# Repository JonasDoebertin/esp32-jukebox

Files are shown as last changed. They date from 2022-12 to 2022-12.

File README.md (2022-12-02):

# Jukebox

An ESP32 based jukebox driven by ESPHome and Home Assistant.

---

About the project: it’s a simple ESP32 based media player that allows scanning cards with RFID tags to select the media to play. Everything will be tight together with ESPHome (for the ESP32 firmware side) and Home Assistant.

It’s a simple 2-layer board with 1.6mm thickness and 4cm x 6cm overall size.

The board features the following main parts:

- ESP32-WROOM-32E as the MCU
- AMS1117-3.3 as a power regulator
- CH340C as the serial converter
- MAX98357AETE+T as a DAC with integrated 3w amp
- connectors for three simple buttons (volume -/+, play/pause)
- connector for an PN532 based RFID module connected via I2C
- connector for a passive broadband speaker

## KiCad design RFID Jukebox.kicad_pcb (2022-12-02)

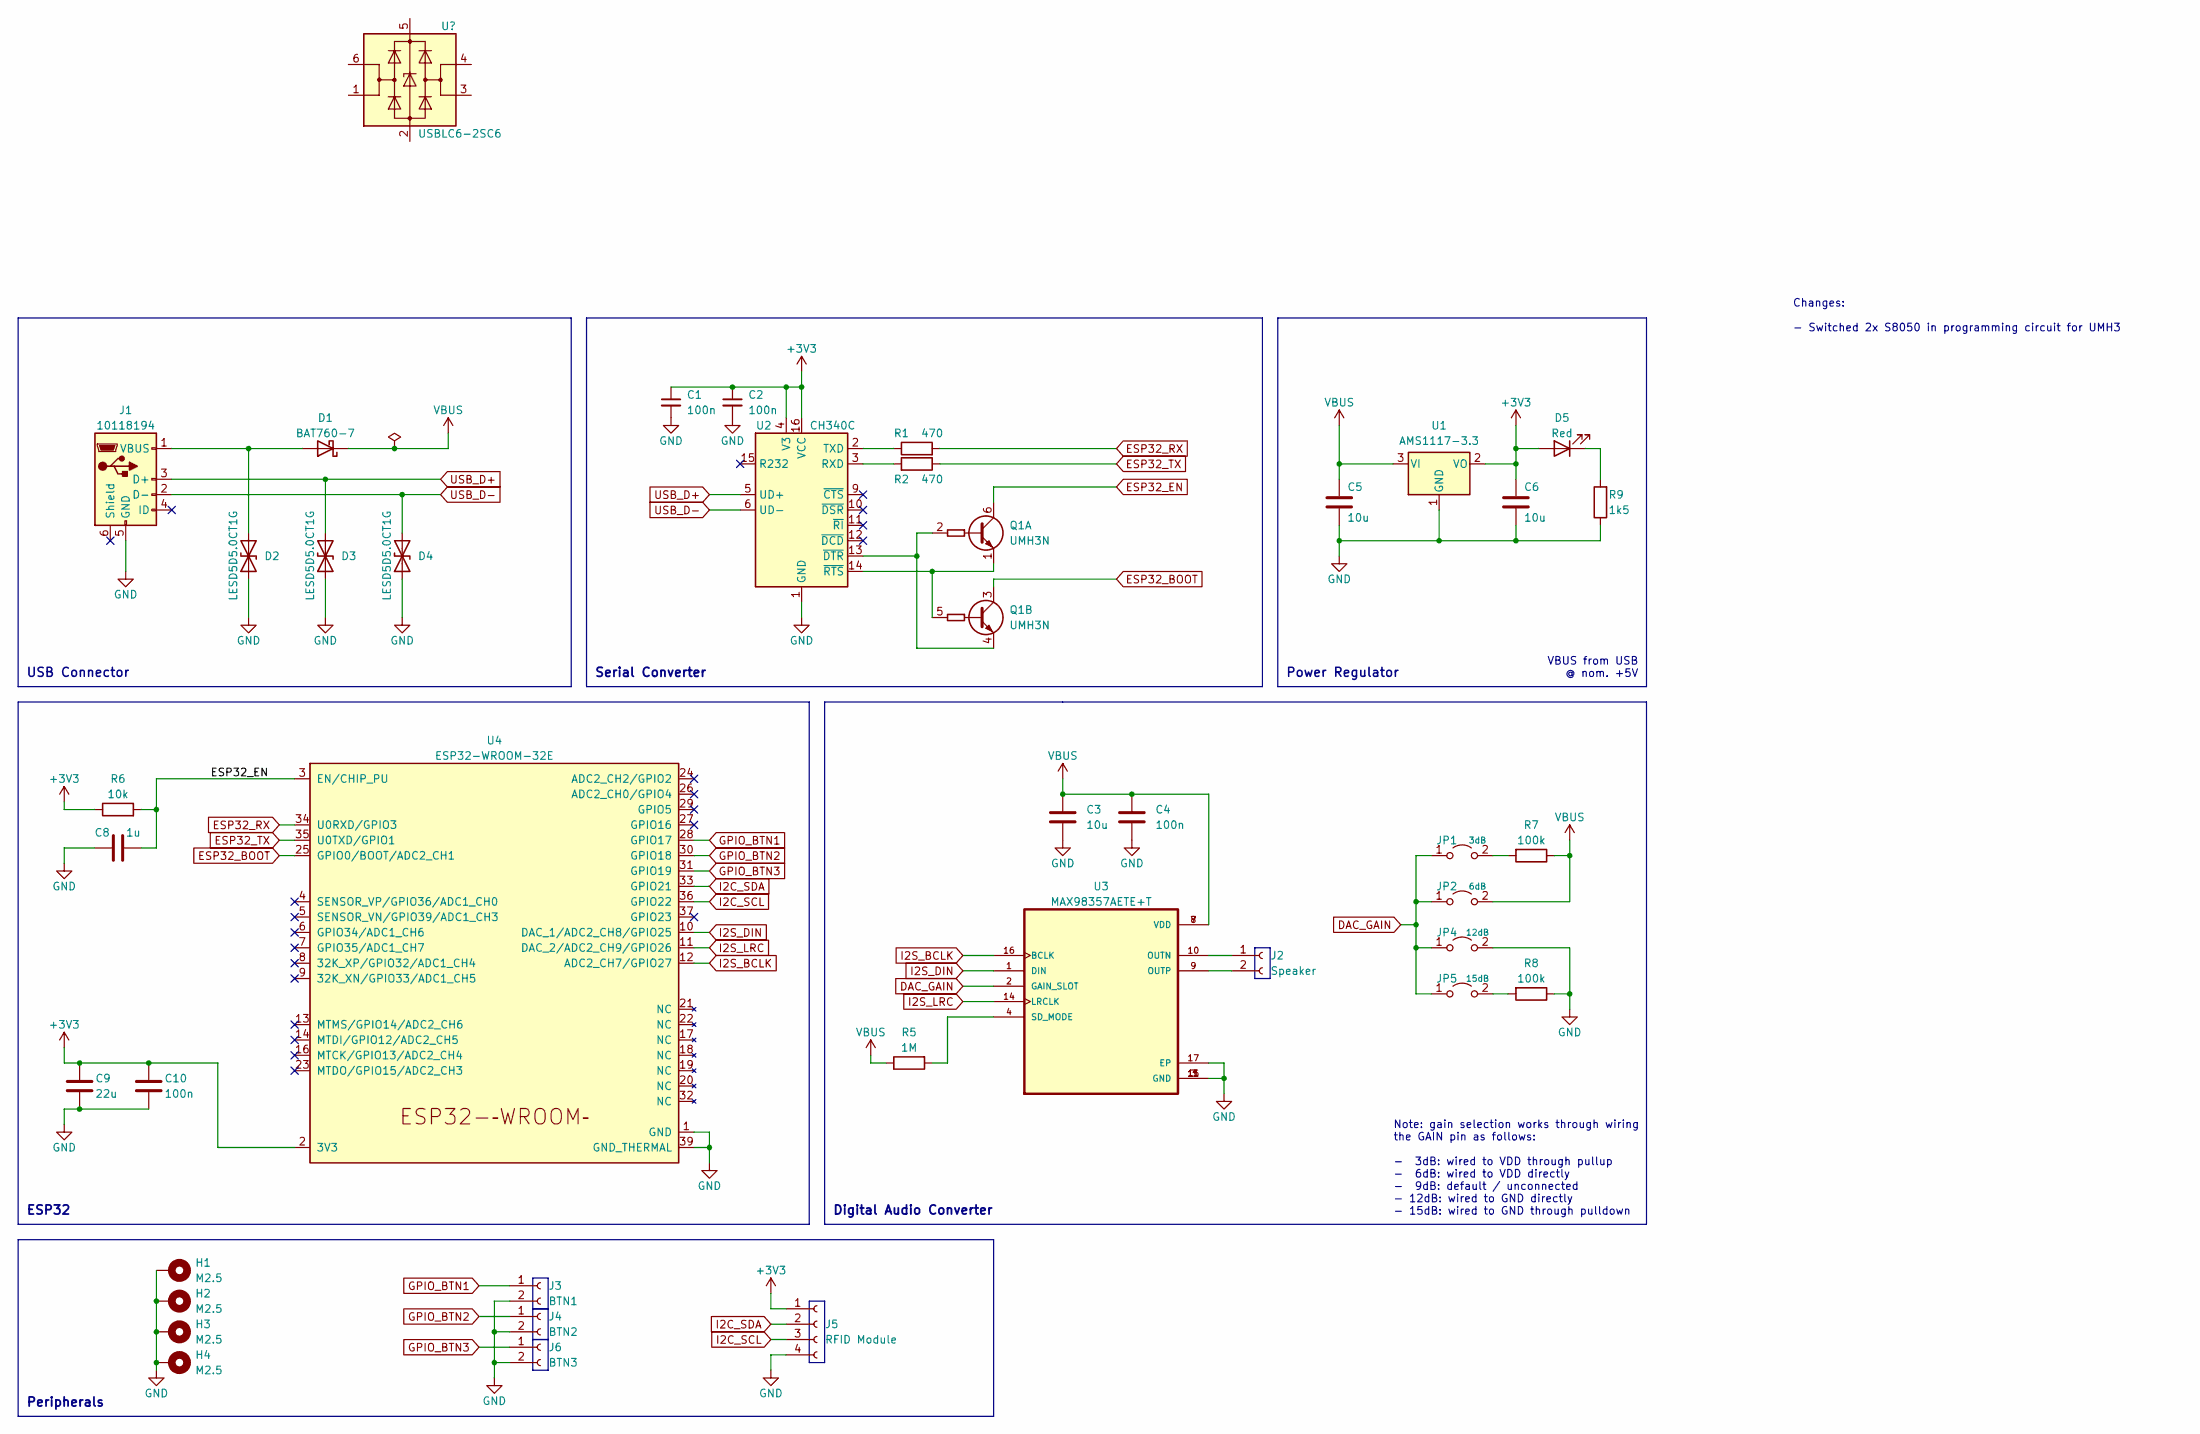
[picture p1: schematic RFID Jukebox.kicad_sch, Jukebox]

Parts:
C1, C2, C4, C10: 100n; C_0603_1608Metric; LCSC C14663
C3: 10u; C_0603_1608Metric; LCSC C96446
C5, C6: 10u; C_0805_2012Metric; LCSC C15850
C8: 1u; C_0603_1608Metric; LCSC C15849
C9: 22u; C_0805_2012Metric; LCSC C45783
D1: BAT760-7; D_SOD-323; LCSC C124187
D2, D3, D4: LESD5D5.0CT1G; D_SOD-523; LCSC C383211
D5: Red; LED_0603_1608Metric; LCSC C2286
H1, H2, H3, H4: M2.5; MountingHole_2.7mm_M2.5_Pad_Via
J1: 10118194; USB_Micro-B_Amphenol_10118194_Horizontal; LCSC C132563
J2: Speaker; Molex_KK-254_AE-6410-02A_1x02_P2.54mm_Vertical
J3: BTN1; Molex_KK-254_AE-6410-02A_1x02_P2.54mm_Vertical
J4: BTN2; Molex_KK-254_AE-6410-02A_1x02_P2.54mm_Vertical
J5: RFID Module; Molex_KK-254_AE-6410-04A_1x04_P2.54mm_Vertical
J6: BTN3; Molex_KK-254_AE-6410-02A_1x02_P2.54mm_Vertical
JP1: 3dB; PinHeader_1x02_P2.54mm_Vertical
JP2: 6dB; PinHeader_1x02_P2.54mm_Vertical
JP4: 12dB; PinHeader_1x02_P2.54mm_Vertical
JP5: 15dB; PinHeader_1x02_P2.54mm_Vertical
Q1: UMH3N; SOT-363_SC-70-6; LCSC C62892
R1, R2: 470; R_0603_1608Metric; LCSC C23179
R5: 1M; R_0805_2012Metric; LCSC C17514
R6: 10k; R_0603_1608Metric; LCSC C25804
R7, R8: 100k; R_0603_1608Metric; LCSC C25803
R9: 1k5; R_0603_1608Metric; LCSC C22843
U1: AMS1117-3.3; SOT-223-3_TabPin2; LCSC C6186
U2: CH340C; SOIC-16_3.9x9.9mm_P1.27mm; LCSC C84681
U3: MAX98357AETE+T; TQFN-16-1EP_3x3mm_P0.5mm_EP1.23x1.23mm; LCSC C910544
U4: ESP32-WROOM-32E; LCSC C701341

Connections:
+3V3: C1.1, C2.1, C6.1, C9.1, C10.1, D5.2 (A), J5.1, R6.1, U1.2 (VO), U2.4 (V3), U2.16 (VCC), U4.2 (3V3)
DAC_GAIN: JP1.1 (A), JP2.1 (A), JP4.1 (A), JP5.1 (A), U3.2 (GAIN_SLOT)
ESP32_BOOT: Q1.3 (C2), U4.25 (GPIO0/BOOT/ADC2_CH1)
ESP32_EN: C8.2, Q1.6 (C1), R6.2, U4.3 (EN/CHIP_PU)
ESP32_RX: R1.2, U4.34 (U0RXD/GPIO3)
ESP32_TX: R2.1, U4.35 (U0TXD/GPIO1)
GND: C1.2, C2.2, C3.2, C4.2, C5.2, C6.2, C8.1, C9.2, C10.2, D2.1 (A1), D3.1 (A1), D4.1 (A1), H1.1, H2.1, H3.1, H4.1, J1.5 (GND), J3.2, J4.2, J5.4, J6.2, JP4.2 (B), R8.1, R9.1, U1.1 (GND), U2.1 (GND), U3.3 (GND), U3.11 (GND), U3.15 (GND), U3.17 (EP), U4.1 (GND), U4.15 (GND), U4.38 (GND), U4.39 (GND_THERMAL)
GPIO_BTN1: J3.1, U4.28 (GPIO17)
GPIO_BTN2: J4.1, U4.30 (GPIO18)
GPIO_BTN3: J6.1, U4.31 (GPIO19)
I2C_SCL: J5.3, U4.36 (GPIO22)
I2C_SDA: J5.2, U4.33 (GPIO21)
I2S_BCLK: U3.16 (BCLK), U4.12 (ADC2_CH7/GPIO27)
I2S_DIN: U3.1 (DIN), U4.10 (DAC_1/ADC2_CH8/GPIO25)
I2S_LRC: U3.14 (LRCLK), U4.11 (DAC_2/ADC2_CH9/GPIO26)
unnamed: D1.2 (A), D2.2 (A2), J1.1 (VBUS)
unnamed: D5.1 (K), R9.2
unnamed: J2.1, U3.10 (OUTN)
unnamed: J2.2, U3.9 (OUTP)
unnamed: JP1.2 (B), R7.2
unnamed: JP5.2 (B), R8.2
unnamed: Q1.1 (E1), Q1.5 (B2), U2.14 (~RTS)
unnamed: Q1.2 (B1), Q1.4 (E2), U2.13 (~DTR)
unnamed: R1.1, U2.2 (TXD)
unnamed: R2.2, U2.3 (RXD)
unnamed: R5.2, U3.4 (SD_MODE)
USB_D+: D3.2 (A2), J1.3 (D+), U2.5 (UD+)
USB_D-: D4.2 (A2), J1.2 (D-), U2.6 (UD-)
VBUS: C3.1, C4.1, C5.1, D1.1 (K), JP2.2 (B), R5.1, R7.1, U1.3 (VI), U3.7 (VDD), U3.8 (VDD)

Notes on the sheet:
Digital Audio Converter
Note: gain selection works through wiring the GAIN pin as follows: - 3dB: wired to VDD through pullup - 6dB: wired to VDD directly - 9dB: default / unconnected - 12dB: wired to GND directly - 15dB: wired to GND through pulldown
ESP32
USB Connector
VBUS from USB @ nom. +5V
Changes: - Switched 2x S8050 in programming circuit for UMH3
Power Regulator
Serial Converter
Peripherals

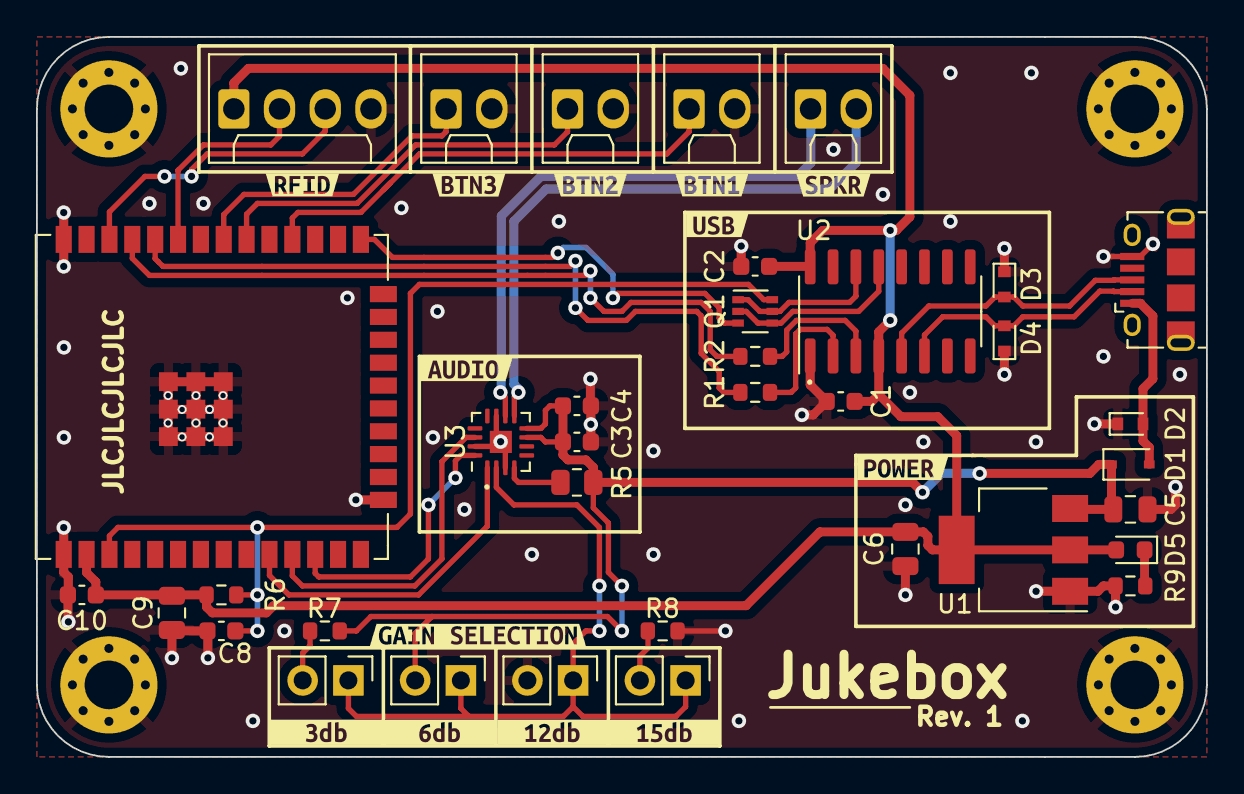
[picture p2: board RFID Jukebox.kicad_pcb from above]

Board: 2 copper layers, 65.0 x 40.0 mm, 53 parts (0 on the bottom side), 29 nets.

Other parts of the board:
kibuzzard-6380B75E: G***; kibuzzard-6380B75E
kibuzzard-63885EFC: G***; kibuzzard-63885EFC
kibuzzard-63886C2C: G***; kibuzzard-63886C2C
kibuzzard-63886C6D: G***; kibuzzard-63886C6D
kibuzzard-63886C09: G***; kibuzzard-63886C09
kibuzzard-63886C18: G***; kibuzzard-63886C18
kibuzzard-63886C48: G***; kibuzzard-63886C48
kibuzzard-63886C53: G***; kibuzzard-63886C53
kibuzzard-63886C64: G***; kibuzzard-63886C64
kibuzzard-63886C79: G***; kibuzzard-63886C79
kibuzzard-6387301B: G***; kibuzzard-6387301B
kibuzzard-63873011: G***; kibuzzard-63873011
kibuzzard-63873069: G***; kibuzzard-63873069
